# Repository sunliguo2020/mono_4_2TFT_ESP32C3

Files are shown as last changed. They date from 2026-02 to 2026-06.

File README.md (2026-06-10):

## ESP32C3_4.2寸鱼鹰全反射类墨水屏

原作者 沙发下的土豆  来自于嘉立创开源广场 [esp32c3_4.2寸鱼鹰全反射类墨水屏]( https://oshwhub.com/bob_yang/esp32c3_4-2-cun-lei-mo-shui-ping )

以下摘自开源广场介绍：

## 项目简介

- 学习ESP32C3低功耗控制，编译环境为ESP-IDF，屏幕为鱼鹰全反射类墨水屏，SPI通讯，可设置低功耗与睡眠模式。
- 学习LVGL的UI设计，使用GUIguider快速布局UI界面。
- 学习http通讯，控制电脑开关机，查询电脑开关机状态，学习通过api查询抖音粉丝数。
- 学习ntp网络校时。
- 学习OPT3001光照传感器，中断唤醒deepsleep。
- 学习人体红外AS312传感器，控制有人存在时更新UI界面。
- 学习使用AHT30温湿度传感器，与opt3001共用i2c总线。
- 学习使用TP4056进行锂电池充电管理，使用DW03进行电池充放电保护。
- 学习ADC测量电池电量，通过PMOS控制电池检测。
- 使用ME6210A33PG低功耗LDO，直接将3.7v电压降到3.3V
- 通过按键进行lightleep唤醒，并使用api将电脑主机开机。

## 项目功能

本设计是基于ESP32C3单片机设计的DIY功能板，系统在光照低于设置阈值时，会进行睡眠模式，此时ESP32C3进入deepsleep模式，adc采集停止，恢复光照时会进行deepsleep唤醒，白天进入lightsleep，每分钟采集一次温湿度，当人体红外检测室内有人时，会进行wifi的一些业务逻辑更新；设置有两个独立按键，功能分别为远程将电脑开机和复位按键。

## 项目参数

- 本设计采用ESP32C3可以进行wifi通讯，有两种低功耗睡眠模模式。
- 本设计采用鱼鹰全反射屏，屏幕没有背光，屏幕有低功耗和睡眠模式，使用功耗更低，刷新频率可以到16HZ。
- 选用全数字型温湿度传感器AHT30，具有较宽的温度测量范围，可以更准确的显示室内的温湿度；
- 选用OPT3001光照传感器，可以通过寄存器设置阈值，使中断引脚根据设置阈值进行高低电平切换，从而控制低功耗的唤醒；
- AS312人体红外传感器，可以通过红外判断室内有没有人存在，如果没有人存在，可以跳过wifi的一些业务逻辑，可以达到降低功耗的目的；
- 使用TP4056进行充电，充电电流可以达到1A,并带有DW03进行电池保护；
- 通过PMOS控制ADC采集的通断，减少ADC电池电压不采集时的漏电流；
- 通过一个ME6210A33PG的LDO进行3.3v降压供电，供电电流500ma，低压降LDO；

## 复刻过程

#### 1、将pcb中所有的0402封装更换为0603封装

注意到这个pcb空间较为宽裕，所以将上面原来0402封装的元件都改为0603封装。主要是以前准备的电容电阻都是0603封装的。

#### 2、嘉立创打板

#### 3、淘宝购买元件

| 序号 | | 数量 | 价格 |
| ---- | :---: | ---- | ---- |
| 1 | AS312 | 1 | 1.75 |
| 2 | ESP32-C3-WROOM-02-N4 | 1 | 7.8  |
| 3 | 鱼鹰光电4.2寸全反射TFT单色屏300*400无背光16Hz | 1 | 43 |

#### 4、焊接

主要是AHT30温湿度 和OPT3001光照 这个两个元件比较难焊接。可以使用加热台先焊接这两个元件。

pfc底座也是一个难点。

#### 5、软件部分

- 安装esp-idf环境
  - 使用ESP-IDF Installation Manager （EIM）离线安装

- vscode安装esp-idf插件

错误1：

```
Python binary path not found. Please check your Python configuration.
```

错误2：

```
The "path" argument must be of type string. Received undefined
```

错误3：

```
Error while getting targets from ESP-IDF: Error: File not found: C:\Users\sunliguo\esp\esp-idf\tools\idf_py_actions\constants.py
```

 最后发现是在C:\Espressif\tools下的 Microsoft.v6.0.1.PowerShell_profile.ps1 有语法错误。 

文件：C:\Espressif\tools\Microsoft.v6.0.1.PowerShell_profile.ps1

把：$previous = $env:’_IDF.PY_COMPLETE’
改成：$previous = ${env:_IDF.PY_COMPLETE}

把：$env:’_IDF.PY_COMPLETE’ = ‘powershell_source’
改成：${env:_IDF.PY_COMPLETE} = ‘powershell_source’

把：$env:’_IDF.PY_COMPLETE’ = $previous
改成：${env:_IDF.PY_COMPLETE} = $previous

#### 6、编译烧录

修改wifi名和密码，pc开机的密钥 ，抖音获取的粉丝数的参数

烧录的时候，需要按下重置按钮。

### 7、字体补全

如果屏幕显示中出现方框（中文字体缺失），说明 GUI Guider 生成的字体文件未包含这些字符。**三种修复方法**：

#### 方法一：GUI Guider 中重新生成

1. 打开 GUI Guider 项目文件
2. 在 UI 设计界面中，找到对应的文本输入框
3. 输入完整的中文文本（如"今日天气"、"明日天气"）
4. 点击"Generate Code"重新生成代码
5. 重新编译烧录即可

#### 方法二：命令行工具 lv_font_conv

```
# 从字体文件中提取并添加缺失字符
lv_font_conv --font SourceHanSansSC-Bold.otf --size 24 \
  --font FontAwesome5-Solid+Brands+Regular.woff --size 16 --format lvgl \
  --symbols "今日天气明℃" \
  --output lv_font_weather_24.c
```

#### 方法三：代码中改用英文字体（快速解决方案）

如果只是少数几个中文字符需要显示，可以直接在代码中将字体改为 `&lv_font_montserratMedium_16`（英文字体，始终可用），同时将文本改为英文：

```c
lv_label_set_text(ui->screen_main_label_5, "W\nE\nA\nT\nH\nE\nR");
lv_obj_set_style_text_font(ui->screen_main_label_5, &lv_font_montserratMedium_16, 0);
```

## 屏幕布局

本设备使用 4.2 寸鱼鹰全反射类墨水屏，分辨率 300×400 像素。主屏幕布局如下：

有效显示宽度290像素

```
┌──────────────────────────────────────┐
│  ┌─ 顶部栏 (y=4, 290x52) ──────────┐ │
│  │ WiFi图标(5,1)       光照图标     │ │
│  │                    (135,2)       │ │
│  │ 人体存在图标(170,4) 电池符号     │ │
│  │                   (221,4)        │ │
│  │ WiFi文字  光照值(135,28)          │ │
│  │ (5,32)    电池百分比(221,28)     │ │
│  └──────────────────────────────────┘ │
│                                       │
│  ┌─ 时间区域 (y=61, 289x112) ──────┐ │
│  │  日期 (居中, 字体SMG_32)    ↻   │ │
│  │  ┌──────────────────────────┐    │ │
│  │  │  88  :  88               │    │ │
│  │  │ (字体SMG_90)             │    │ │
│  │  └──────────────────────────┘    │ │
│  └──────────────────────────────────┘ │  ← 间距 5px
│  ┌─ 温湿度 (y=178, 290x65) ──────┐ │
│  │ [温度] 25.5  │  [湿度] 60.3    │ │
│  │ (竖排带边框) │ (竖排带边框)    │ │
│  │ (字体SMG_40) │ (字体SMG_40)    │ │
│  └──────────────────────────────┘ │  ← 间距 5px
│  ┌─ 天气 (y=248, 290x152) ───────┐ │
│  │  天气描述 / 温度 / 湿度         │ │
│  │  (多标签重叠动态显示)           │ │
│  └──────────────────────────────┘ │
│                                       │
│  ┌─ 睡眠屏幕 ───────────────────────┐ │
│  │  背景图片(sleep2_RGB565)         │ │
│  │  文字: "苟命要紧"(右上角)        │ │
│  └──────────────────────────────────┘ │
└──────────────────────────────────────┘
```

### 各区域详细说明

| 区域 | 容器 | 位置 (x,y) | 大小 (w×h) | 内容 |
|---|---|---|---|---|
| 顶部栏 | `screen_main_cont_top_bar` | (5, 4) | 290×52 | WiFi图标/文字、光照图标/值、人体存在图标、电池符号/百分比 |
| 时间区域 | `screen_main_cont_time` | (5, 61) | 289×112 | 日期、时间(时:分)、时间同步符号(↻) |
| 温湿度 | `screen_main_cont_temp_humi` | (5, 178) | 290×65 | 温度标签/数值（左）、湿度标签/数值（右） |
| 天气 | `screen_main_cont_bottom` | (5, 248) | 290×152 | 天气描述/温度/湿度（多标签重叠动态切换，占满底部） |
| 睡眠屏幕 | `screen_sleep` | 全屏 | 300×400 | 睡眠背景图 + "苟命要紧"标签 |

### 顶部栏详细布局

**第一行 (y=0~25):**
- WiFi图标 `screen_main_img_1`: (5, 1), 33×31, 图片资源 `_wifi_down_I4_33x31`(离线) / `_wifi_fill_I4_33x31`(在线)
- 光照图标 `screen_main_img_2`: (135, 2), 29×25, 图片资源 `_light_val_I4_29x25`
- 人体存在图标 `screen_main_img_5`: (170, 4), 36×37, 图片资源 `_Human_Presence_Sensor_RGB565A8_36x37`（有人时显示，无人时隐藏）
- 电池符号 `screen_main_label_17`: (221, 4), 52×22, LVGL电池图标符号，根据电量动态切换（EMPTY/1/2/3/FULL）

**第二行 (y=26~50):**
- WiFi文字 `screen_main_label_wifi`: (5, 32), 33×12, 居中显示"WiFi", 字体 montserratMedium_12
- 光照值 `screen_main_label_light_val`: (135, 28), 60×14, 字体 montserratMedium_16
- 电池百分比 `screen_main_label_bat_val`: (221, 28), 52×14, 右对齐, 字体 montserratMedium_16, 格式"100%"

### 时间区域详细布局

区域容器 `screen_main_cont_time`: (5, 61), 289×112, 白底圆角边框

- 日期标签 `screen_main_label_date`: (0, 1), 233×28, 字体 SMG_32, 居中对齐, 格式"2026-01-30"
- 时间同步符号 `screen_main_label_time_update`: (241, 4), 30×23, 字体 SourceHanSansSCBold_24, 显示 LV_SYMBOL_LOOP(↻)
- 子容器 `screen_main_cont_2`: (2, 32), 281×89, 仅顶部边框
  - 小时 `screen_main_label_time_hour`: (-1, -10), 140×85, 字体 SMG_90, 左对齐
  - 冒号 `screen_main_label_1`: (131, -20), 22×82, 字体 SMG_90, 居中对齐
  - 分钟 `screen_main_label_time_min`: (150, -10), 136×82, 字体 SMG_90, 居中对齐

> 注：`screen_main_label_time_update` 显示时间同步状态，同步中显示 ↻，可改为 ✅ 表示同步完成。

### 温湿度区域详细布局

区域容器 `screen_main_cont_temp_humi`: (5, 178), 290×65, 白底圆角边框

温湿度区域采用**左右平分布局**：左侧显示温度，右侧显示湿度。每侧包含竖排标签（带黑色边框圆角）和数值。

**左侧温度区域（0~145）：**
- 温度标签 `screen_main_label_10`: (5, 5), 30×50, 竖排文本"温\n度", 字体 SourceHanSansSCBold_20, 带黑色边框圆角, 居中对齐
- 温度值 `screen_main_label_temp_val`: (38, 8), 120×48, 字体 SMG_40, 格式"25.5", 初始值"0.0"

**右侧湿度区域（145~290）：**
- 湿度标签 `screen_main_label_8`: (155, 5), 30×50, 竖排文本"湿\n度", 字体 SourceHanSansSCBold_20, 带黑色边框圆角, 居中对齐
- 湿度值 `screen_main_label_humi_val`: (188, 8), 120×48, 字体 SMG_40, 格式"60.3", 初始值"0.0"

### 天气区域详细布局

区域容器 `screen_main_cont_bottom`: (5, 248), 290×152, 白底圆角边框

天气区域占据屏幕最底部，全宽显示。使用多个位置重叠的标签，通过 `UI_MSG_WEATHER` 消息动态控制显示：

| 标签 | 位置 (x,y) | 大小 (w×h) | 字体 | 用途 |
|---|---|---|---|---|
| `screen_main_label_weather` | (5, 5) | 97×108 | montserratMedium_16 | 主标签（显示天气图标） |
| `screen_main_label_5` | (0, 0) | 107×118 | SourceHanSansSCBold_24 | 天气描述文本（如"晴"） |
| `screen_main_label_20` | (0, 0) | 107×118 | SourceHanSansSCBold_24 | 温度（如"28°C"） |
| `screen_main_label_run_hour` | (0, 0) | 107×118 | SourceHanSansSCBold_24 | 湿度（如"60%"） |
| `screen_main_label_19` | (0, 0) | 107×118 | SourceHanSansSCBold_24 | 备用 |
| `screen_main_label_18` | (0, 0) | 107×118 | SourceHanSansSCBold_24 | 备用 |
| `screen_main_label_run_min` | (0, 0) | 107×118 | SourceHanSansSCBold_24 | 备用 |
| `screen_main_label_2` | (0, 0) | 107×118 | SourceHanSansSCBold_24 | 备用 |

### 睡眠屏幕详细布局

| 控件 | 位置 (x,y) | 大小 (w×h) | 内容 |
|---|---|---|---|
| `screen_sleep_img_1` | (0, 0) | 301×399 | 睡眠背景图 `_sleep2_RGB565_301x399` |
| `screen_sleep_label_1` | (189, 6) | 37×108 | 文本"苟命要紧"，带黑色边框圆角，字体 SourceHanSansSCBold_24 |

### UI 消息系统（动态更新）

`lvgl_ui.c` 通过消息队列（`ui_msg_t`）在后台任务中更新 UI：

| 消息类型 | 函数接口 | 更新内容 |
|---|---|---|
| `UI_MSG_WIFI_ONLINE` | `wifi_online()` | WiFi图标切换为在线图标 `_wifi_fill_I4_33x31` |
| `UI_MSG_WIFI_OFFLINE` | `wifi_downline()` | WiFi图标切换为离线图标 `_wifi_down_I4_33x31` |
| `UI_MSG_TIME_LABELS` | `lvgl_ui_set_time_labels()` | 更新日期、时、分文本 |
| `UI_MSG_TIME_SYMBOL` | `lvgl_ui_set_time_update_symbol()` | 更新时间同步符号（↻ 等） |
| `UI_MSG_TEMP_HUMI` | `lvgl_ui_set_temp_humi()` | 更新温湿度数值（保留1位小数） |
| `UI_MSG_LIGHT_LUX` | `lvgl_ui_set_light_lux()` | 更新光照强度数值（lux） |
| `UI_MSG_BATTERY` | `lvgl_ui_set_battery()` | 更新电池百分比和电池图标（EMPTY/1/2/3/FULL） |
| `UI_MSG_PRESENCE` | `lvgl_ui_set_presence()` | 人体存在：显示/隐藏人体存在图标 |
| `UI_MSG_WEATHER` | `lvgl_ui_set_weather()` | 更新天气描述、温度、湿度/图标 |
| `UI_MSG_SLEEP_SCREEN` | `lvgl_ui_show_sleep_screen()` | 切换主屏/睡眠屏 |

## 改进过程

### 1、蓝牙配网问题

原来的wifi名和密码是写死的，我想改成第一次蓝牙配网模式。

#### 配网流程

##### 1、启动流程

```
app_main()
  ├─ NVS 初始化
  ├─ LVGL 初始化（显示 GUI）
  ├─ 传感器初始化（AHT30、OPT3001、BATTERY、AS312）
  └─ 主循环（每 100ms 运行一次状态机）
```

##### 2、状态机流程

```
STATE_INIT
  ├─ 有 WiFi 凭据？→ STATE_WIFI_CONNECTING
  └─ 无 WiFi 凭据？→ STATE_BLE_PROVISIONING

STATE_WIFI_CONNECTING
  ├─ WiFi 已连接？→ STATE_WIFI_CONNECTED（调用 on_wifi_connected）
  └─ 30秒超时？→ STATE_BLE_PROVISIONING

STATE_BLE_PROVISIONING
  ├─ 启动 BLE 广播（设备名: "ESP32-C3-WiFi"）
  ├─ 等待手机发送数据（格式: ssid:xxx,pwd:xxx）
  ├─ 收到数据后累积到缓冲区
  ├─ 解析成功？→ 保存到 NVS → 设置标志位
  └─ 主循环检测到标志位 → STATE_PROVISIONING_DONE

STATE_PROVISIONING_DONE
  ├─ 关闭 BLE
  ├─ 重新加载 WiFi 凭据
  ├─ 连接 WiFi
  ├─ WiFi 已连接？→ STATE_WIFI_CONNECTED
  └─ 30秒超时？→ STATE_PROVISIONING_WIFI_FAIL

STATE_PROVISIONING_WIFI_FAIL
  └─ 重新进入 BLE 配网模式

STATE_WIFI_CONNECTED
  ├─ 设置默认时间（非阻塞）
  ├─ 启动时间同步（后台任务）
  ├─ 注册 HTTP 更新回调（PC 状态、抖音粉丝）
  ├─ 启动睡眠灯光
  └─ 更新 WiFi 图标（wifi_online）

```

##### 3、手机配网操作

```
1. 设备启动 → 无 WiFi 凭据 → 自动进入 BLE 配网模式
2. 手机打开 BLE 扫描 → 找到 "ESP32-C3-WiFi"
3. 手机连接设备 → 找到特征值 UUID 0xFFE1
4. 手机写入数据（分两次发送）:
   第一次: "ssid:rizhixinxi,pwd:"
   第二次: "ruizhi2016"
5. 设备累积接收 → 解析成功 → 保存到 NVS
6. 设备关闭 BLE → 连接 WiFi
7. WiFi 连接成功 → 更新图标 → 开始正常工作

```

##### 4、关键文件

| 文件 | 功能 |
| --- | --- |
| main/main.c | 主循环、状态机、配网完成回调 |
| components/ble_wifi/ble_wifi.c | BLE 服务、数据接收、凭据解析 |
| components/Wifi_hw_Y/Wifi_hw_Y.c | WiFi 初始化、事件处理、NVS 存储 |

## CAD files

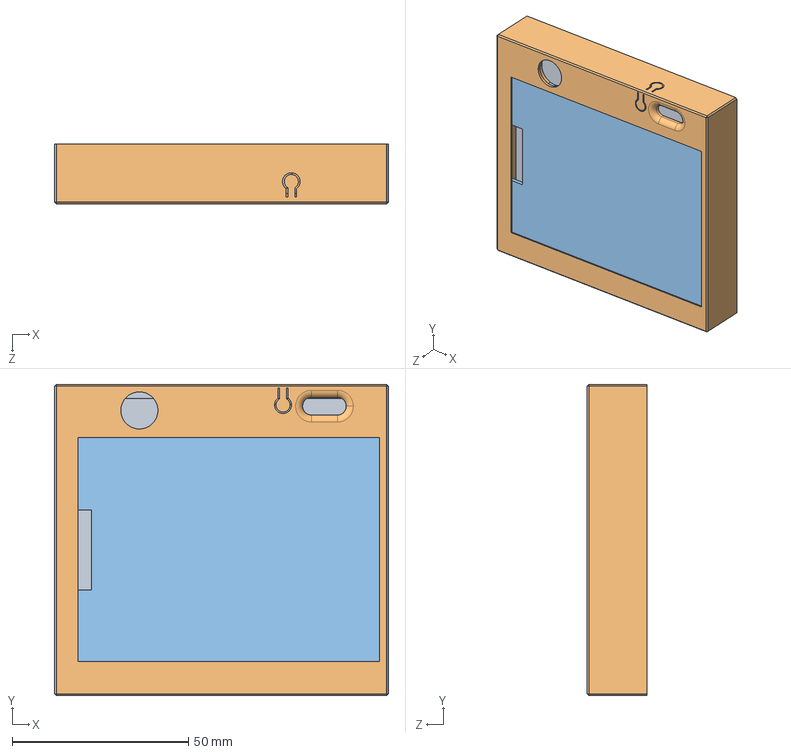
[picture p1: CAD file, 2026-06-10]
pcb/全反射屏外壳.STEP
94.6 x 88.2 x 17.0 mm

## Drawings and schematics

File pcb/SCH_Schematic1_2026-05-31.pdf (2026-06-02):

OPT3001光照 | AHT30温湿度

# 全反屏24pin

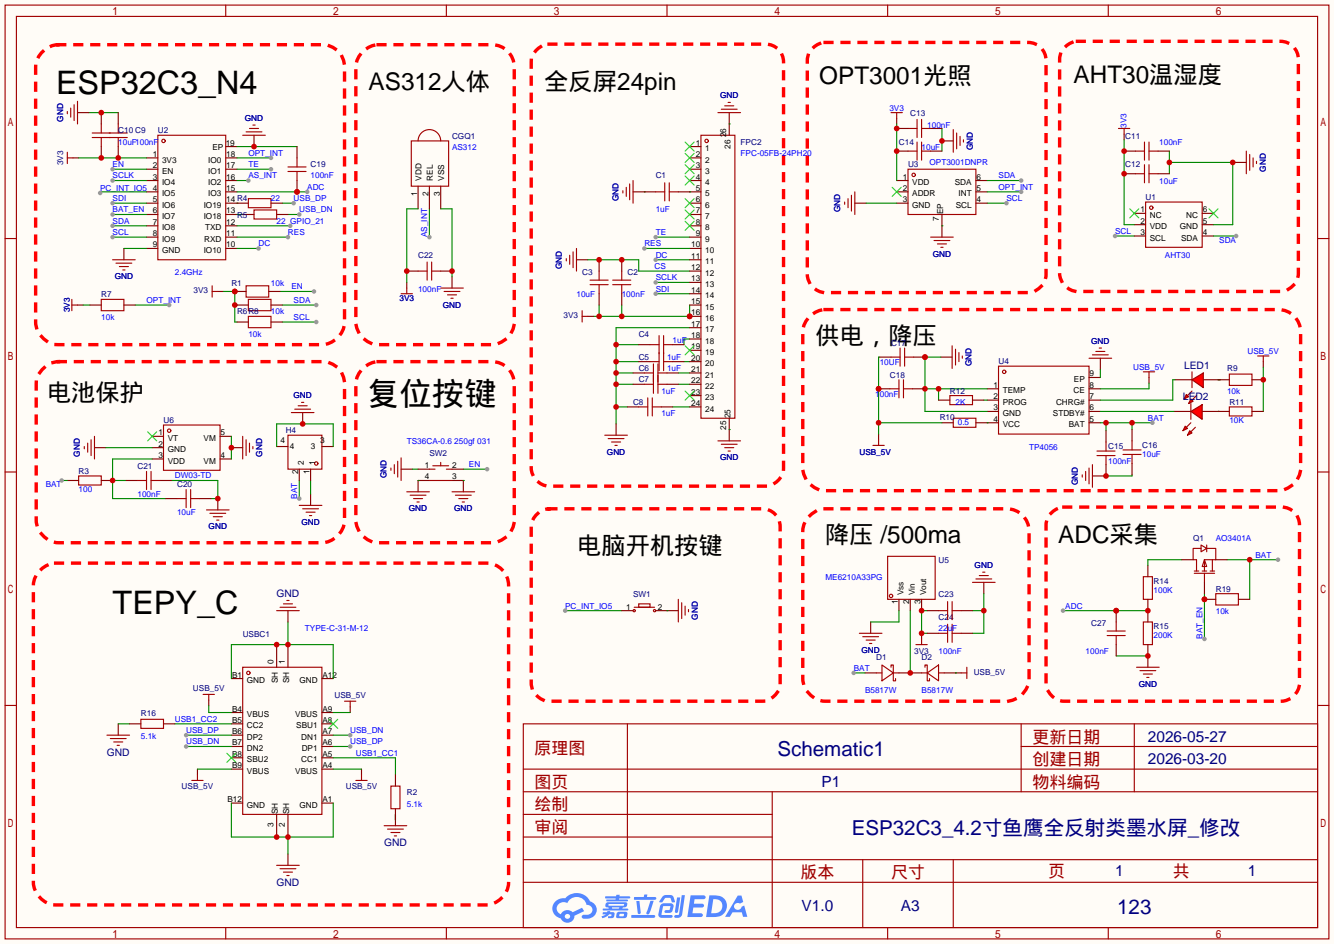
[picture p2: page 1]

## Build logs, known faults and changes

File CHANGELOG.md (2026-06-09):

# 项目变更日志

## [2026-06-09] 天气区域汉字显示 + 数码管温度 + 今明两天天气

### 1. 天气区域显示中文

**涉及文件**：`components/GUI/generated/guider_fonts/lv_font_weather_20.c`、`components/GUI/generated/guider_fonts/lv_font_weather_24.c`、`components/GUI/generated/setup_scr_screen_main_bottom.c`、`components/weather/weather.c`、`components/lvgl_display/lvgl_ui.c`

**修改内容**：
- 新增 `lv_font_weather_20` 天气中文字体（使用系统 simhei.ttf 生成，包含：晴多云阴小雨中大雨暴雨雷阵雨雪雾霾少间北南东西风转℃日出）
- 新增 `lv_font_weather_24` 加大版中文字体（用于℃符号显示）
- 天气标签字体从 `lv_font_SourceHanSansSCBold_20`（稀疏字体，仅含66个汉字）改为 `lv_font_weather_20`
- `weather_apply_to_ui()` 移除 `translate_weather()` / `translate_wind()` 英文翻译，直接使用 API 返回的中文原文
- 温度数字改用 `lv_font_SMG_40`（40px LED数码管字体），居中显示
- ℃符号用独立标签 `screen_main_label_18` 以 24px 字体显示

### 2. 风力解析修复

**涉及文件**：`components/weather/weather.c`

**修改内容**：
- API `windScale` 字段可能是数值类型（如 `"windScaleDay": 3`）而非字符串，原解析代码仅处理字符串
- 新增 `parse_wind_scale()` 函数同时支持字符串和数值两种格式
- `ui_msg_t` 中 `weather.humi` 字段从 `char[16]` 扩大到 `char[32]`，解决 UTF-8 中文截断

### 3. 今明两天天气同时显示

**涉及文件**：`components/weather/weather.c`、`components/GUI/generated/setup_scr_screen_main_bottom.c`、`components/lvgl_display/lvgl_ui.c`

**修改内容**：
- `parse_weather_json()` 新增 `parse_one_day()` 通用解析函数，通过查找第二个 `"fxDate"` 定位第二天数据
- 新增 `s_weather_*_tmrw` 变量组存储第二天（明天）天气
- HTTP 缓冲区从 4096 扩大到 8192，解压缓冲区固定为 8192，确保完整 JSON 不被截断
- 新增 `screen_main_label_2` 标签在底部区域第三行显示第二天天气

### 4. 日出信息中文显示

**涉及文件**：`components/weather/weather.c`

**修改内容**：
- 第三行格式从 `R:04:46` 改为 `日出04:46`
- `R` 原为 "Rise"（日出）缩写，现直接显示中文

### 5. 天气每30分钟自动刷新

**涉及文件**：`main/main.c`

**修改内容**：
- 主循环新增 `WEATHER_INTERVAL_MS = 30 * 60 * 1000` 定时器
- 每30分钟调用 `weather_force_update()` + `weather_poll_once()` + `weather_apply_to_ui()` 刷新显示

---

## [2026-06-08] 和风天气获取与显示 + 温湿度显示修复 + 屏幕布局优化

### 1. 和风天气 API 集成

**涉及文件**：`components/weather/weather.c`、`components/weather/include/weather.h`

**修改内容**：
- 接入和风天气 API（`mg7fc3p9rj.re.qweatherapi.com`），获取实时天气数据
- 实现 gzip 解压：使用 miniz 库对压缩响应解压（纯 deflate 模式）
- 使用 `crt_bundle_attach` 全局证书包验证 TLS 连接
- 新增 `weather_poll_once_blocking()` 异步阻塞函数（信号量同步）
- 时间同步等待超时调整为 60 秒

### 2. 栈溢出修复

**涉及文件**：`components/weather/weather.c`、`main/main.c`

**问题根因**：TLS 握手需要大量栈空间（约 10-12KB），main 任务栈不足导致崩溃

**修复方案**：
- 将天气请求移至独立高栈任务（16384 字节），通过信号量实现异步阻塞
- 在 `app_main` 中调用 `weather_poll_once_blocking()` 等待任务完成

### 3. 初始化顺序优化

**涉及文件**：`main/main.c`

**修改内容**：调整 `app_main` 初始化顺序，解决 LVGL 初始化卡死问题
1. 传感器初始化（AHT30/OPT3001/BATTERY/AS312）— 不依赖屏幕
2. WiFi 连接（阻塞等待 STATE_WIFI_CONNECTED）
3. SNTP 时间同步（60 秒超时）
4. 天气请求（独立高栈任务）
5. LVGL 屏幕初始化
6. 推送传感器/天气数据到 UI
7. 启动 sleep 任务

### 4. 温湿度传感器数据显示修复

**涉及文件**：`components/AHT30_Y/AHT30_Y.c`、`components/GUI/generated/gui_guider.c`

**修复内容**：
- AHT30_Y.c：补充缺失的 `s_consecutive_failures` 和 `MAX_CONSECUTIVE_FAILURES` 声明
- gui_guider.c：`setup_ui()` 中添加 `setup_scr_screen_main_temp_humi()` 调用

### 5. 屏幕布局重构

**涉及文件**：`components/GUI/generated/setup_scr_screen_main_temp_humi.c`、`components/GUI/generated/setup_scr_screen_main_bottom.c`

**布局调整**：
- 温湿度区域改为**左右平分布局**（290×65）：
  - 左侧温度：竖排标签"温\n度"（30×50）+ SMG_40 数值（120×48）
  - 右侧湿度：竖排标签"湿\n度"（30×50）+ SMG_40 数值（120×48）
- 天气区域移至屏幕底部（5, 248, 290×152），全宽显示
- 各区域之间保留 5px 一致间距

### 6. 内存竞争修复

**涉及文件**：`components/sleep/sleep.c`、`main/main.c`

**修复内容**：
- 移除 sleep 任务中对 `weather_is_busy()` 的调用
- 天气请求在 sleep 任务启动前完成，两个高栈任务错开运行
- 移除 sleep.c 中 `sleep_step_enter_sleep()` 中重复的天气等待逻辑

### 7. 文档更新

**涉及文件**：`README.md`

**更新内容**：屏幕布局 ASCII 图、详细尺寸表、温湿度/天气区域详细说明

---

## [2026-05-27] BLE 配网 + WiFi 自动重连 + 电池 ADC 修正

### 1. BLE 配网功能（WiFi 失败后自动开启）

**涉及文件**：`main/main.c`、`components/ble_wifi/ble_wifi.c`、`components/ble_wifi/include/ble_wifi.h`

**修改内容**：
- 主循环改为**状态机**方式运行，每 100ms 轮询一次
- 新增状态：`STATE_INIT` → `STATE_WIFI_CONNECTING` → `STATE_BLE_PROVISIONING` → `STATE_PROVISIONING_DONE` → `STATE_WIFI_CONNECTED`
- WiFi 连接失败（30 秒超时）自动进入 BLE 配网模式
- BLE 配网完成后不立即重启，而是尝试连接 WiFi
- 配网成功后执行后续初始化（时间同步、睡眠任务、HTTP 更新）

**关键修复**：
- 使用 `volatile` 标志位替代事件队列，避免 NimBLE 任务中操作队列导致死锁
- BLE 数据分片接收：添加累积接收缓冲区，支持数据分多次写入特征值
- 结束符识别：手机发送的是字面 `\n`（`5c 6e`）而非换行符 `0x0A`，添加兼容处理

### 2. WiFi 连接优化

**涉及文件**：`components/Wifi_hw_Y/Wifi_hw_Y.c`、`components/Wifi_hw_Y/include/Wifi_hw_Y.h`

**修改内容**：
- 移除 `wifi_download_init()` 中的阻塞等待（`xEventGroupWaitBits` + `portMAX_DELAY`）
- 移除 `wifi_hw_init()` 中的重复 NVS 初始化（NVS 已在 `main.c` 中初始化）
- 添加 `wifi_wait_connected(TickType_t ticks_to_wait)` 非阻塞等待接口
- 添加 `wifi_save_to_nvs()` 和 `wifi_load_from_nvs()` 用于 BLE 配网保存/读取凭据
- 修复配网后 WiFi 连接崩溃：`esp_netif_create_default_wifi_sta()` 前先销毁旧的 netif
- 修复 WiFi 图标不更新：在 `IP_EVENT_STA_GOT_IP` 事件中调用 `wifi_online()`

### 3. BLE 初始化修复

**涉及文件**：`components/ble_wifi/ble_wifi.c`

**修改内容**：
- 启动 BLE 前先关闭 WiFi 驱动（`esp_wifi_deinit()`），解决 WiFi/BLE 射频冲突
- BLE 关闭后重新初始化 WiFi 驱动

### 4. 任务看门狗修复

**涉及文件**：`main/main.c`

**修改内容**：
- 主循环改用状态机非阻塞方式，移除所有阻塞等待
- 在 `sdkconfig` 中禁用任务看门狗（`CONFIG_ESP_TASK_WDT_EN=n`）

### 5. LVGL 初始化顺序修复

**涉及文件**：`main/main.c`

**修改内容**：
- 先初始化 LVGL 显示，再尝试 WiFi 连接
- 避免 WiFi 阻塞等待时 LVGL 未初始化导致 UI 更新崩溃

### 6. 电池 ADC 分压比修正

**涉及文件**：`components/BATTERY_Y/BATTERY_Y.c`

**修改内容**：
- 分压电路从 10k+22k 改为 100k+200k（实际焊接值）
- `BAT_DIV_NUM`: 32 → 300, `BAT_DIV_DEN`: 22 → 200
- `Vbat = Vadc * 300 / 200 = Vadc * 1.5`
- 添加详细的硬件连接注释（ADC 引脚、分压电路、MOSFET 控制、电量计算公式）
- 添加函数注释说明初始化、读取、控制流程

### 7. PC_INT_IO5 开机功能

**涉及文件**：`main/main.c`、`components/sleep/sleep.c`

**功能说明**：
- GPIO5 作为 PC 开机按钮，下降沿触发中断
- 按下 IO5 后发送 HTTP 请求唤醒 PC
- 支持从 light sleep 唤醒时检测 IO5 唤醒源

---

## 状态机流程图

```
app_main()
  ├─ NVS 初始化
  ├─ LVGL 初始化（显示 GUI）
  ├─ 传感器初始化（AHT30、OPT3001、BATTERY、AS312）
  └─ 主循环（每 100ms 运行一次状态机）

STATE_INIT
  ├─ 有 WiFi 凭据？→ STATE_WIFI_CONNECTING
  └─ 无 WiFi 凭据？→ STATE_BLE_PROVISIONING

STATE_WIFI_CONNECTING
  ├─ WiFi 已连接？→ STATE_WIFI_CONNECTED
  └─ 30秒超时？→ STATE_BLE_PROVISIONING

STATE_BLE_PROVISIONING
  ├─ 启动 BLE 广播（设备名: "ESP32-C3-WiFi"）
  ├─ 等待手机发送数据（格式: ssid:xxx,pwd:xxx）
  ├─ 解析成功？→ 保存到 NVS → 设置标志位
  └─ 主循环检测到标志位 → STATE_PROVISIONING_DONE

STATE_PROVISIONING_DONE
  ├─ 关闭 BLE
  ├─ 重新加载 WiFi 凭据
  ├─ 连接 WiFi
  ├─ WiFi 已连接？→ STATE_WIFI_CONNECTED
  └─ 30秒超时？→ STATE_PROVISIONING_WIFI_FAIL

STATE_PROVISIONING_WIFI_FAIL
  └─ 重新进入 BLE 配网模式

STATE_WIFI_CONNECTED
  ├─ 设置默认时间（非阻塞）
  ├─ 启动时间同步（后台任务）
  ├─ 注册 HTTP 更新回调（PC 状态、抖音粉丝）
  ├─ 启动睡眠灯光
  └─ 更新 WiFi 图标（wifi_online）
```

## 手机配网操作

```
1. 设备启动 → 无 WiFi 凭据 → 自动进入 BLE 配网模式
2. 手机打开 BLE 扫描 → 找到 "ESP32-C3-WiFi"
3. 手机连接设备 → 找到特征值 UUID 0xFFE1
4. 手机写入数据（分两次发送）:
   第一次: "ssid:rizhixinxi,pwd:ruizhi2016"
5. 设备累积接收 → 解析成功 → 保存到 NVS
6. 设备关闭 BLE → 连接 WiFi
7. WiFi 连接成功 → 更新图标 → 开始正常工作

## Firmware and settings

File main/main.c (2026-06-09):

#include <stdio.h>

#include "freertos/FreeRTOS.h"
#include "freertos/task.h"

#include "esp_lvgl_port.h"
#include "lvgl.h"
#include "esp_log.h"
#include "esp_task_wdt.h"

#include "lvgl_display.h"
#include "Wifi_hw_Y.h"
#include "hw_time_Y.h"
#include "sleep.h"
#include "AHT30_Y.h"
#include "OPT3001_Y.h"
#include "BATTERY_Y.h"
#include "AS312_Y.h"
#include "esp_sleep.h"
#include "ble_wifi.h"
#include "nvs_flash.h"
#include "esp_wifi.h"
#include "weather.h"
#include "at_cmd.h"

#define WAKE_BTN_GPIO 5
#define OPT3001_INT_TEST 0
#define OPT3001_INT_TEST_PERIOD_MS 200
#define OPT3001_INT_TEST_LUX_POLL_MS 1000
#define OPT3001_TEST_LOW_LUX 5.0f
#define OPT3001_TEST_HIGH_LUX 20.0f
#define OPT3001_DEEPSLEEP_TEST 0
#define OPT3001_DEEPSLEEP_WAKE_LOW 1
#define OPT3001_DEEPSLEEP_WAKE_SEC 5
#define AS312_GPIO GPIO_NUM_2
#define TAG "MAIN"

// WiFi 连接超时时间（毫秒）
#define WIFI_CONNECT_TIMEOUT_MS 30000

// 系统状态枚举
typedef enum {
    STATE_INIT,                    // 初始状态
    STATE_WIFI_CONNECTING,         // WiFi 连接中（初始尝试）
    STATE_WIFI_CONNECTED,          // WiFi 已连接
    STATE_BLE_PROVISIONING,        // BLE 配网中
    STATE_PROVISIONING_DONE,       // 配网完成，正在连接 WiFi
    STATE_PROVISIONING_WIFI_FAIL,  // 配网后 WiFi 连接失败
} system_state_t;

static system_state_t s_state = STATE_INIT;
static TickType_t s_state_start_tick = 0;

// 配网完成标志（用于从 BLE 回调通知主任务）
// 使用 volatile 标志位而非队列，避免在 NimBLE 任务中操作队列导致死锁
static volatile bool s_provisioning_done_flag = false;

static void handle_io5_wakeup(void) {
    sleep_notify_io5_wake();
}

/**
 * @brief 配网完成回调：BLE 收到 WiFi 凭据后调用
 * 
 * 这个回调在 NimBLE 任务中执行，不能直接调用 WiFi 相关函数。
 * 设置标志位，由主循环轮询检查。
 */
static void on_provisioning_done(void)
{
    ESP_LOGI(TAG, "Provisioning done, setting flag for main task...");
    s_provisioning_done_flag = true;
}

/**
 * @brief 进入 BLE 配网状态
 * 关闭 WiFi 驱动，启动 BLE
 */
static void enter_ble_provisioning(void)
{
    ESP_LOGI(TAG, "Entering BLE provisioning mode...");

    // 关闭 WiFi 底层驱动，释放射频资源给 BLE 使用
    esp_wifi_stop();
    esp_wifi_deinit();

    // 注册配网完成回调
    ble_wifi_register_done_cb(on_provisioning_done);

    esp_err_t ret = ble_wifi_init();
    if (ret != ESP_OK) {
        ESP_LOGE(TAG, "BLE init failed: %s", esp_err_to_name(ret));
    }

    s_state = STATE_BLE_PROVISIONING;
    s_state_start_tick = xTaskGetTickCount();
}

/**
 * @brief 进入 WiFi 连接状态
 */
static void enter_wifi_connecting(void)
{
    ESP_LOGI(TAG, "Entering WiFi connecting mode...");
    wifi_hw_init();
    s_state = STATE_WIFI_CONNECTING;
    s_state_start_tick = xTaskGetTickCount();
}

/**
 * @brief WiFi 连接成功后的初始化
 * 注意：此函数在状态机中调用，不能阻塞！
 * 时间同步在后台任务中进行，不阻塞主循环
 */
static void on_wifi_connected(void)
{
    ESP_LOGI(TAG, "WiFi connected! Performing post-connection init...");
    s_state = STATE_WIFI_CONNECTED;

    // 设置默认时间（非阻塞）
    hw_time_set_default_if_unset();
    // 启动时间同步（在后台任务中进行，不阻塞）
    hw_time_sync_start();

    // esp_sleep_wakeup_cause_t cause = esp_sleep_get_wakeup_cause();
    uint64_t gpio_wakeup = esp_sleep_get_gpio_wakeup_status();
    if (gpio_wakeup & (1ULL << WAKE_BTN_GPIO)) {
        handle_io5_wakeup();
    }

    // 天气请求由 app_main 在显示初始化前完成，这里不再重复调用
}

/**
 * @brief 状态机主循环处理函数
 * 每次主循环迭代时调用，非阻塞地处理状态转换
 */
static void state_machine_run(void)
{
    switch (s_state) {
        case STATE_INIT: {
            // 初始状态：尝试 WiFi 连接
            wifi_load_from_nvs();
            bool has_wifi_creds = (strlen(MY_SSID) > 0 && strlen(MY_PASSWORD) > 0);

            if (has_wifi_creds) {
                ESP_LOGI(TAG, "WiFi credentials found, attempting to connect...");
                enter_wifi_connecting();
            } else {
                ESP_LOGI(TAG, "No WiFi credentials, starting BLE provisioning...");
                enter_ble_provisioning();
            }
            break;
        }

        case STATE_WIFI_CONNECTING: {
            // WiFi 连接中，检查是否已连接或超时
            if (wifi_is_connected()) {
                on_wifi_connected();
                return;
            }

            TickType_t elapsed = xTaskGetTickCount() - s_state_start_tick;
            if (elapsed >= pdMS_TO_TICKS(WIFI_CONNECT_TIMEOUT_MS)) {
                ESP_LOGW(TAG, "WiFi connection timeout after %d ms", WIFI_CONNECT_TIMEOUT_MS);
                enter_ble_provisioning();
            }
            break;
        }

        case STATE_WIFI_CONNECTED: {
            // WiFi 已连接，无需额外操作
            break;
        }

        case STATE_BLE_PROVISIONING: {
            // BLE 配网中，检查配网完成标志
            if (s_provisioning_done_flag) {
                s_provisioning_done_flag = false;
                ESP_LOGI(TAG, "Provisioning done, connecting WiFi...");
                // 关闭 BLE
                ble_wifi_deinit();
                // 重新加载 WiFi 凭据
                wifi_load_from_nvs();
                // 进入 WiFi 连接状态
                enter_wifi_connecting();
                s_state = STATE_PROVISIONING_DONE;
                s_state_start_tick = xTaskGetTickCount();
            }
            break;
        }

        case STATE_PROVISIONING_DONE: {
            // 配网完成，正在连接 WiFi
            if (wifi_is_connected()) {
                on_wifi_connected();
                return;
            }

            TickType_t elapsed = xTaskGetTickCount() - s_state_start_tick;
            if (elapsed >= pdMS_TO_TICKS(WIFI_CONNECT_TIMEOUT_MS)) {
                ESP_LOGW(TAG, "WiFi connection failed after provisioning");
                s_state = STATE_PROVISIONING_WIFI_FAIL;
            }
            break;
        }

        case STATE_PROVISIONING_WIFI_FAIL: {
            // 配网后 WiFi 连接失败，重新开启 BLE
            ESP_LOGW(TAG, "WiFi failed after provisioning, restarting BLE...");
            enter_ble_provisioning();
            break;
        }

        default:
            break;
    }
}

void app_main(void)
{
    esp_err_t ret;

    // 禁用任务看门狗，避免 LVGL 渲染时触发看门狗超时
    // LVGL 任务在渲染大屏幕时可能占用 CPU 超过默认的 5 秒超时
    esp_task_wdt_deinit();

    // =========================
    // NVS INIT
    // =========================
    ret = nvs_flash_init();

    if (ret == ESP_ERR_NVS_NO_FREE_PAGES ||
        ret == ESP_ERR_NVS_NEW_VERSION_FOUND) {

        ESP_ERROR_CHECK(nvs_flash_erase());
        ret = nvs_flash_init();
    }

    ESP_ERROR_CHECK(ret);

    uint64_t gpio_wakeup = esp_sleep_get_gpio_wakeup_status();
    ESP_LOGI("main", "wakeup cause=%d gpio_mask=0x%08x%08x",
             (int)esp_sleep_get_wakeup_cause(), (uint32_t)(gpio_wakeup >> 32),
             (uint32_t)gpio_wakeup);

    // Install GPIO ISR service once for IO5 wake and AS312 motion.
    esp_err_t isr_ret = gpio_install_isr_service(0);
    if (isr_ret != ESP_OK && isr_ret != ESP_ERR_INVALID_STATE) {
        ESP_LOGW("main", "gpio ISR service init failed: 0x%x",
                 (unsigned)isr_ret);
    }

    // 先初始化传感器和 Wi-Fi，暂不启动屏幕
    aht30_y_init();
    aht30_y_start();
    opt3001_y_init();
    battery_y_init();
    as312_y_init(AS312_GPIO);
    opt3001_y_config_interrupt(OPT3001_TEST_LOW_LUX, OPT3001_TEST_HIGH_LUX,
                               true);

    // Wi-Fi 连接状态机（会阻塞等待连接）
    while (s_state != STATE_WIFI_CONNECTED) {
        state_machine_run();
        vTaskDelay(pdMS_TO_TICKS(100));
    }

    // 等待时间同步完成（TLS 证书验证需要正确的时间）
    ESP_LOGI(TAG, "waiting for time sync before weather...");
    hw_time_wait_for_sync(60000);

    // 先获取天气数据（屏幕初始化前），缓存数据
    weather_poll_once_blocking();

    // ========== 初始化 LVGL 显示 ==========
    lv_display_t *disp = lvgl_display_init();
    if (!disp) {
        abort();
    }

    lvgl_port_lock(portMAX_DELAY);
    lvgl_gui_init();
    lvgl_ui_show_sleep_screen(false);
    lvgl_port_unlock();
    lvgl_ui_wait_idle(500);

    // 将缓存的天气数据推送到 UI
    weather_apply_to_ui();

    // 把已缓存的传感器数据推送到 UI
    aht30_y_read_update_ui();
    opt3001_y_read_update_ui();
    battery_y_read_update_ui();

    // 初始化 AT 指令 UART 串口
    at_cmd_init();

    // 屏幕显示完毕后再启动 sleep 任务
    sleep_start_light();

#if OPT3001_DEEPSLEEP_TEST
    opt3001_y_run_deepsleep_test(OPT3001_DEEPSLEEP_WAKE_LOW,
                                 OPT3001_DEEPSLEEP_WAKE_SEC);
#endif

#if OPT3001_INT_TEST
    opt3001_y_start_int_test(OPT3001_INT_TEST_PERIOD_MS,
                             OPT3001_INT_TEST_LUX_POLL_MS);
    return;
#endif

    // 定时任务间隔
    TickType_t last_temp_humi_tick = xTaskGetTickCount();
#define TEMP_HUMI_INTERVAL_MS 3000  // 每 3 秒读取一次

    TickType_t last_weather_tick = xTaskGetTickCount();
#define WEATHER_INTERVAL_MS (30 * 60 * 1000)  // 每 30 分钟更新天气

    // 主循环：非阻塞地处理状态机
    while (1) {
        // 运行状态机（非阻塞）
        state_machine_run();

        TickType_t now = xTaskGetTickCount();

        // 定时读取温湿度传感器并更新 UI
        if ((now - last_temp_humi_tick) >= pdMS_TO_TICKS(TEMP_HUMI_INTERVAL_MS)) {
            aht30_y_read_update_ui();
            opt3001_y_read_update_ui();
            last_temp_humi_tick = now;
        }

        // 定时更新天气（每 30 分钟）
        if ((now - last_weather_tick) >= pdMS_TO_TICKS(WEATHER_INTERVAL_MS)) {
            ESP_LOGI(TAG, "weather refresh (30 min interval)...");
            weather_force_update();  // 强制刷新缓存
            if (wifi_is_connected()) {
                weather_poll_once();  // 获取新数据（非阻塞）
                if (weather_is_valid()) {
                    weather_apply_to_ui();  // 更新 UI
                }
            }
            last_weather_tick = xTaskGetTickCount();
        }

        // 短暂延时，让其他任务（如 LVGL）有机会运行
        vTaskDelay(pdMS_TO_TICKS(100));
    }
}

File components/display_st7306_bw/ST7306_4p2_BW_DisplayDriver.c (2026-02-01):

#include "ST7306_4p2_BW_DisplayDriver.h"

#include <stdlib.h>
#include <string.h>

#include "driver/gpio.h"
#include "driver/spi_common.h"
#include "driver/spi_master.h"
#include "esp_err.h"
#include "esp_heap_caps.h"
#include "freertos/FreeRTOS.h"
#include "freertos/task.h"

#define ST7306_SPI_DEFAULT_CLOCK_HZ (40 * 1000 * 1000)

#ifndef SPI_MAX_DMA_LEN
#define SPI_MAX_DMA_LEN 4096
#endif

#define ST7306_SPI_MAX_CHUNK SPI_MAX_DMA_LEN

#define ST7306_COL_START 0x05
#define ST7306_COL_END (ST7306_COL_START + (ST7306_4P2_BW_LCD_DATA_WIDTH / 3) - 1)
#define ST7306_ROW_START 0x00
#define ST7306_ROW_END (ST7306_4P2_BW_LCD_DATA_HEIGHT - 1)

struct st7306_4p2_bw_t {
    st7306_4p2_bw_config_t cfg;
    spi_device_handle_t spi;
    uint8_t *display_buffer;
    bool hpm_mode;
    bool lpm_mode;
    bool owns_bus;
};

#define ST7306_CHECK(expr)           \
    do {                             \
        esp_err_t _err = (expr);     \
        if (_err != ESP_OK) {        \
            return _err;             \
        }                            \
    } while (0)

static void st7306_delay_ms(uint32_t ms)
{
    if (ms == 0) {
        return;
    }
    vTaskDelay(pdMS_TO_TICKS(ms));
}

static void st7306_gpio_init(const st7306_4p2_bw_config_t *cfg)
{
    gpio_reset_pin(cfg->pin_dc);
    gpio_set_direction(cfg->pin_dc, GPIO_MODE_OUTPUT);
    gpio_set_level(cfg->pin_dc, 0);

    gpio_reset_pin(cfg->pin_rst);
    gpio_set_direction(cfg->pin_rst, GPIO_MODE_OUTPUT);
    gpio_set_level(cfg->pin_rst, 1);

    if (!cfg->use_hw_cs && cfg->pin_cs >= 0) {
        gpio_reset_pin(cfg->pin_cs);
        gpio_set_direction(cfg->pin_cs, GPIO_MODE_OUTPUT);
        gpio_set_level(cfg->pin_cs, 1);
    }
}

static void st7306_hw_reset(const st7306_4p2_bw_t *dev)
{
    gpio_set_level(dev->cfg.pin_rst, 1);
    st7306_delay_ms(10);
    gpio_set_level(dev->cfg.pin_rst, 0);
    st7306_delay_ms(10);
    gpio_set_level(dev->cfg.pin_rst, 1);
    st7306_delay_ms(10);
}

static esp_err_t st7306_spi_tx(st7306_4p2_bw_t *dev, const uint8_t *data, size_t len, bool hold_cs)
{
    if (!dev || !data || len == 0) {
        return ESP_ERR_INVALID_ARG;
    }

    bool bus_acquired = false;
    if (hold_cs) {
        esp_err_t err = spi_device_acquire_bus(dev->spi, portMAX_DELAY);
        if (err != ESP_OK) {
            return err;
        }
        bus_acquired = true;
    }

    if (!dev->cfg.use_hw_cs && dev->cfg.pin_cs >= 0 && hold_cs) {
        gpio_set_level(dev->cfg.pin_cs, 0);
    }

    size_t offset = 0;
    while (offset < len) {
        size_t chunk = len - offset;
        if (chunk > ST7306_SPI_MAX_CHUNK) {
            chunk = ST7306_SPI_MAX_CHUNK;
        }

        spi_transaction_t t = {0};
        t.length = chunk * 8;
        t.tx_buffer = data + offset;

        if (dev->cfg.use_hw_cs && hold_cs && (offset + chunk) < len) {
            t.flags = SPI_TRANS_CS_KEEP_ACTIVE;
        }

        if (!dev->cfg.use_hw_cs && dev->cfg.pin_cs >= 0 && !hold_cs) {
            gpio_set_level(dev->cfg.pin_cs, 0);
        }

        esp_err_t err = spi_device_polling_transmit(dev->spi, &t);

        if (!dev->cfg.use_hw_cs && dev->cfg.pin_cs >= 0 && !hold_cs) {
            gpio_set_level(dev->cfg.pin_cs, 1);
        }

        if (err != ESP_OK) {
            if (!dev->cfg.use_hw_cs && dev->cfg.pin_cs >= 0 && hold_cs) {
                gpio_set_level(dev->cfg.pin_cs, 1);
            }
            if (bus_acquired) {
                spi_device_release_bus(dev->spi);
            }
            return err;
        }

        offset += chunk;
    }

    if (!dev->cfg.use_hw_cs && dev->cfg.pin_cs >= 0 && hold_cs) {
        gpio_set_level(dev->cfg.pin_cs, 1);
    }

    if (bus_acquired) {
        spi_device_release_bus(dev->spi);
    }

    return ESP_OK;
}

static esp_err_t st7306_write_register(st7306_4p2_bw_t *dev, uint8_t value)
{
    gpio_set_level(dev->cfg.pin_dc, 0);
    return st7306_spi_tx(dev, &value, 1, false);
}

static esp_err_t st7306_write_parameter(st7306_4p2_bw_t *dev, uint8_t value)
{
    gpio_set_level(dev->cfg.pin_dc, 1);
    return st7306_spi_tx(dev, &value, 1, false);
}

static esp_err_t st7306_address(st7306_4p2_bw_t *dev)
{
    ST7306_CHECK(st7306_write_register(dev, 0x2A));
    ST7306_CHECK(st7306_write_parameter(dev, ST7306_COL_START));
    ST7306_CHECK(st7306_write_parameter(dev, ST7306_COL_END));

    ST7306_CHECK(st7306_write_register(dev, 0x2B));
    ST7306_CHECK(st7306_write_parameter(dev, ST7306_ROW_START));
    ST7306_CHECK(st7306_write_parameter(dev, ST7306_ROW_END));

    ST7306_CHECK(st7306_write_register(dev, 0x2C));
    return ESP_OK;
}

static esp_err_t st7306_address_window(st7306_4p2_bw_t *dev, uint8_t col_start, uint8_t col_end,
                                       uint8_t row_start, uint8_t row_end)
{
    ST7306_CHECK(st7306_write_register(dev, 0x2A));
    ST7306_CHECK(st7306_write_parameter(dev, col_start));
    ST7306_CHECK(st7306_write_parameter(dev, col_end));

    ST7306_CHECK(st7306_write_register(dev, 0x2B));
    ST7306_CHECK(st7306_write_parameter(dev, row_start));
    ST7306_CHECK(st7306_write_parameter(dev, row_end));

    ST7306_CHECK(st7306_write_register(dev, 0x2C));
    return ESP_OK;
}

static esp_err_t st7306_write_data_rows(st7306_4p2_bw_t *dev, const uint8_t *base, uint32_t stride,
                                        uint32_t row_start, uint32_t row_end,
                                        uint32_t byte_start, uint32_t byte_end)
{
    if (!dev || !base || byte_end < byte_start || row_end < row_start) {
        return ESP_ERR_INVALID_ARG;
    }

    esp_err_t err = spi_device_acquire_bus(dev->spi, portMAX_DELAY);
    if (err != ESP_OK) {
        return err;
    }

    if (!dev->cfg.use_hw_cs && dev->cfg.pin_cs >= 0) {
        gpio_set_level(dev->cfg.pin_cs, 0);
    }

    gpio_set_level(dev->cfg.pin_dc, 1);

    uint32_t len = byte_end - byte_start + 1;
    for (uint32_t row = row_start; row <= row_end; ++row) {
        const uint8_t *ptr = base + (row * stride) + byte_start;

        spi_transaction_t t = {0};
        t.length = len * 8;
        t.tx_buffer = ptr;

        if (dev->cfg.use_hw_cs && row != row_end) {
            t.flags = SPI_TRANS_CS_KEEP_ACTIVE;
        }

        err = spi_device_polling_transmit(dev->spi, &t);
        if (err != ESP_OK) {
            break;
        }
    }

    if (!dev->cfg.use_hw_cs && dev->cfg.pin_cs >= 0) {
        gpio_set_level(dev->cfg.pin_cs, 1);
    }

    spi_device_release_bus(dev->spi);
    return err;
}
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

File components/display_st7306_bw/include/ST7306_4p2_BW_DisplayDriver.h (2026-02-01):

#ifndef ST7306_4P2_BW_DISPLAY_DRIVER_H
#define ST7306_4P2_BW_DISPLAY_DRIVER_H

#include <stdbool.h>
#include <stddef.h>
#include <stdint.h>

#include "MONO_TFT.h"
#include "driver/spi_master.h"
#include "esp_err.h"

#ifdef __cplusplus
extern "C" {
#endif

#define ST7306_COLOR_00 (0x00)
#define ST7306_COLOR_01 (0x01)
#define ST7306_COLOR_10 (0x02)
#define ST7306_COLOR_11 (0x03)

#define ST73XX_COLOR_BLACK ST7306_COLOR_11
#define ST73XX_COLOR_WHITE ST7306_COLOR_00

#ifndef TFT_WIDTH
#define TFT_WIDTH 300
#endif

#ifndef TFT_HEIGHT
#define TFT_HEIGHT 400
#endif

#define ST7306_4P2_BW_LCD_WIDTH TFT_WIDTH
#define ST7306_4P2_BW_LCD_HEIGHT TFT_HEIGHT
#define ST7306_4P2_BW_LCD_DATA_WIDTH (ST7306_4P2_BW_LCD_WIDTH / 2)
#define ST7306_4P2_BW_LCD_DATA_HEIGHT (ST7306_4P2_BW_LCD_HEIGHT / 2)
#define ST7306_4P2_BW_BUFFER_LEN (ST7306_4P2_BW_LCD_WIDTH * ST7306_4P2_BW_LCD_HEIGHT / 4)

typedef struct {
    int pin_dc;
    int pin_rst;
    int pin_cs;
    int pin_sclk;
    int pin_mosi;
    spi_host_device_t spi_host;
    int spi_clock_hz;
    bool use_hw_cs;
} st7306_4p2_bw_config_t;

typedef struct st7306_4p2_bw_t st7306_4p2_bw_t;

esp_err_t st7306_4p2_bw_init(st7306_4p2_bw_t **out, const st7306_4p2_bw_config_t *cfg);
void st7306_4p2_bw_deinit(st7306_4p2_bw_t *dev);

esp_err_t st7306_4p2_bw_fill(st7306_4p2_bw_t *dev, uint8_t data);
esp_err_t st7306_4p2_bw_clear(st7306_4p2_bw_t *dev);
esp_err_t st7306_4p2_bw_write_point(st7306_4p2_bw_t *dev, uint32_t x, uint32_t y, uint16_t data);
esp_err_t st7306_4p2_bw_display(st7306_4p2_bw_t *dev);
esp_err_t st7306_4p2_bw_display_area(st7306_4p2_bw_t *dev, uint32_t x1, uint32_t y1, uint32_t x2, uint32_t y2);

esp_err_t st7306_4p2_bw_low_power_mode(st7306_4p2_bw_t *dev);
esp_err_t st7306_4p2_bw_high_power_mode(st7306_4p2_bw_t *dev);
esp_err_t st7306_4p2_bw_display_on(st7306_4p2_bw_t *dev, bool enabled);
esp_err_t st7306_4p2_bw_display_sleep(st7306_4p2_bw_t *dev, bool enabled);
esp_err_t st7306_4p2_bw_display_inversion(st7306_4p2_bw_t *dev, bool enabled);

uint8_t *st7306_4p2_bw_buffer(st7306_4p2_bw_t *dev);
size_t st7306_4p2_bw_buffer_len(st7306_4p2_bw_t *dev);

#ifdef __cplusplus
}
#endif

#endif

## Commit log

2026-02-01 可以获取主机开关机状态
    [partitions.csv]
2026-02-01 时间可以正常更新显示
2026-03-05 更改屏幕复位引脚，现在功能一切正常
    [partitions.csv]
2026-03-20 API换成自己的
2026-05-24 新增README
2026-05-26 1、更新readme 2、修改wifi密码
2026-05-26 修改AHT30的初始化代码，防止初始化失败重启
2026-05-27 使用AI将蓝牙配网的流程复盘下来
2026-05-27 BAT_ADC_ATTEN ADC_ATTEN_DB_11 这个宏一直有提示，直接修改了
2026-05-27 实现了蓝牙配网的功能
2026-05-27 vscode的配置文件修改
2026-05-27 fix(battery): 修正分压比参数为实际焊接的100k+200k
2026-05-27 docs: 添加项目变更日志 CHANGELOG.md
2026-06-02 fix: 修复人体存在图标显示问题，更新README屏幕布局说明
2026-06-07 feat: 支持多组WiFi凭据存储和自动切换
2026-06-07 fix: 修复温湿度传感器数据显示问题并恢复原始布局
2026-06-08 fix: 修复天气获取和显示问题，添加gzip解压，调整启动顺序
2026-06-08 fix: 调整天气显示区域到屏幕最下面一行
2026-06-08 fix: 减小天气显示区域高度，避免与温湿度数据重叠
2026-06-08 fix: 温湿度改为左右布局显示
2026-06-08 fix: 温湿度显示区域宽度扩展为290，占满全宽
2026-06-08 fix: 减小温湿度数字字体为SMG_40，宽度增至120
2026-06-08 fix: 温湿度高度缩小至80，天气区域上移至y=262
2026-06-08 fix: 进一步压缩温湿度区域高度，天气区域填满屏幕底部
2026-06-08 fix: 温湿度和天气之间增加5像素空隙
2026-06-08 docs: 更新屏幕布局文档至最新状态
2026-06-08 docs: 更新 CHANGELOG.md，添加 2026-06-08 版本变更记录
2026-06-08 fix: 分离天气数据获取和UI更新，先获取数据再初始化屏幕
2026-06-08 feat: 切换3天预报API + 天气区域分行布局
2026-06-08 fix: 温度行字体改为SourceHanSansSCBold_38，修复中文显示方框
2026-06-08 fix: 天气区域字体统一改为已编译的中文字体
2026-06-08 fix: 天气数据改为英文显示，避免中文未嵌入字体问题
2026-06-08 feat: 解析fxDate显示Today/Tomor/Day+2标记天气日期
2026-06-08 fix: 天气日期改为直接显示MM-DD格式，不再显示Today/Tomor/Day+2
2026-06-09 fix: 天气区域显示汉字及数码管温度样式
2026-06-09 feat: 增大℃符号尺寸到24px
2026-06-09 fix: 支持数值型风力等级解析，修复风力不显示问题
2026-06-09 fix: 扩大weather_line缓冲区解决snprintf截断警告
2026-06-09 feat: 天气每30分钟自动刷新
2026-06-09 docs: 更新CHANGELOG.md，添加天气区域汉字显示等变更记录
2026-06-09 feat: 添加AT指令功能(UART1, GPIO6/7)
2026-06-09 fix: main/CMakeLists.txt 添加 at_cmd 依赖修复编译报错
2026-06-09 fix: 第三行明天天气字体改为24px（与第二行℃符号一致）
2026-06-10 外壳文件
    [全反射屏外壳.STEP]
2026-06-10 fix: 字体新增今天明气汉字，修复SourceHanSansSCBold_24.c语法错误
2026-06-10 fix: 去掉温度中间的~符号改用点号分隔
2026-06-10 fix: 小时右对齐+分钟左对齐实现15:00正确显示
2026-06-10 revert: 恢复时间显示到修改前
2026-06-12 fix: 恢复温度格式为最低~最高温（16~28）
2026-06-12 fix: 更新图标字体改为montserratMedium_16以正确显示LV_SYMBOL_LOOP
2026-06-12 fix: 更新图标字体改为montserratMedium_24加大双箭头图标
2026-06-12 fix: 恢复字体文件修复中文显示，时间图标改用24px
